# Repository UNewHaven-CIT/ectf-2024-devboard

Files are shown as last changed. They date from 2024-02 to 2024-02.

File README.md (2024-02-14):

# UNewHaven 2024 eCTF
### Rev A

This is a daughterboard for the MAX78000FT development board, designed for the 2024 eCTF competition.

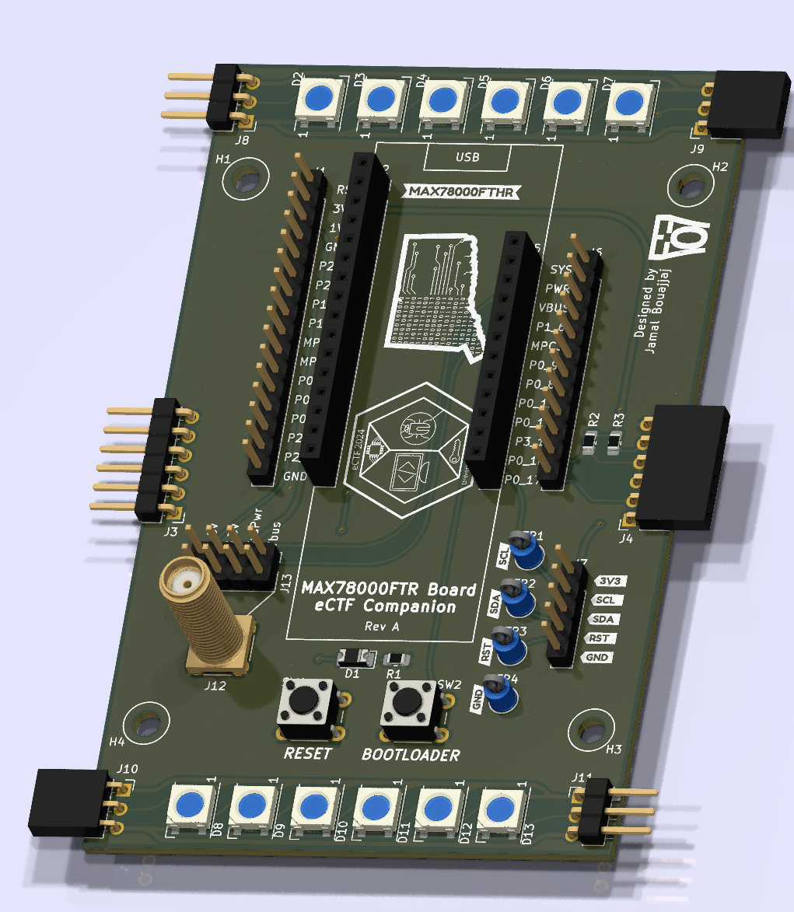
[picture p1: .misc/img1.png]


This was partially inspired by MITRE's own board design, and from a joke gone too far (the leds are what started it all).

# Features
- As the competition has 3 interconnected boards, this design provisions for side-interconnects
- Independent and chain-able WS2812B LEDs on the top of the board, for some true ectf gaming
- Expandable IO for MAX78000FT board
- SMA monitoring for a selection of voltage lines

# License
This project is licensed under GPLv3.

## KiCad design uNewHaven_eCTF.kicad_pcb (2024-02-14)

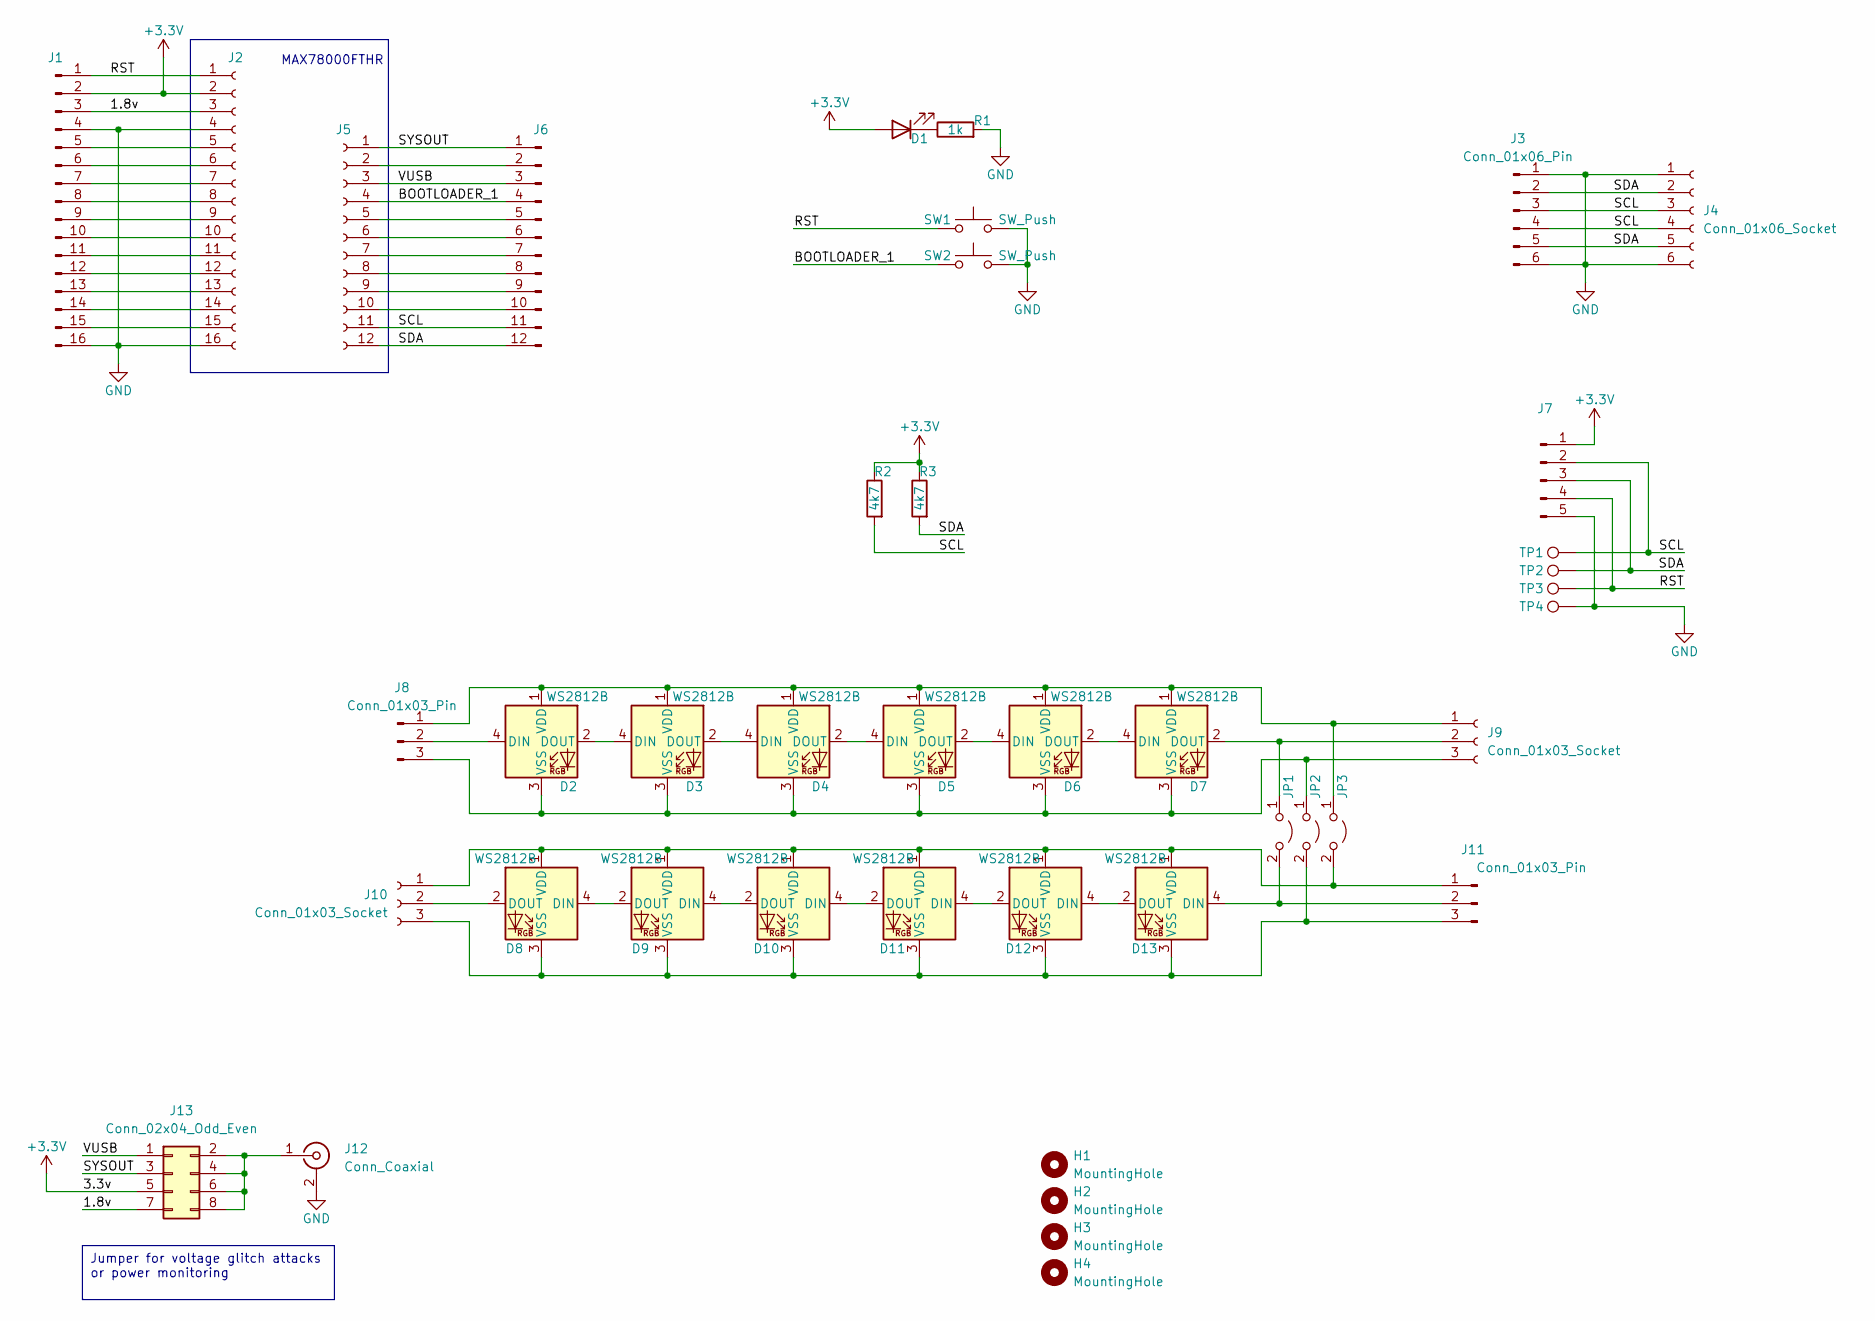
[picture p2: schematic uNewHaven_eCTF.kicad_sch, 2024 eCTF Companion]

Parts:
D1: LED; D_1206_3216Metric_Pad1.42x1.75mm_HandSolder
D2, D3, D4, D5, D6, D7, D8, D9, D10, D11, D12, D13: WS2812B; LED_WS2812B_PLCC4_5.0x5.0mm_P3.2mm
H1, H2, H3, H4: MountingHole; MountingHole_3.2mm_M3_DIN965
J1: Conn_01x16_Pin; PinHeader_1x16_P2.54mm_Vertical
J2: Conn_01x16_Socket; PinSocket_1x16_P2.54mm_Vertical
J3: Conn_01x06_Pin; PinHeader_1x06_P2.54mm_Horizontal
J4: Conn_01x06_Socket; PinSocket_1x06_P2.54mm_Horizontal
J5: Conn_01x12_Socket; PinSocket_1x12_P2.54mm_Vertical
J6: Conn_01x12_Pin; PinHeader_1x12_P2.54mm_Vertical
J7: Conn_01x05_Pin; PinHeader_1x05_P2.54mm_Vertical
J8, J11: Conn_01x03_Pin; PinHeader_1x03_P2.54mm_Horizontal
J9, J10: Conn_01x03_Socket; PinSocket_1x03_P2.54mm_Horizontal
J12: Conn_Coaxial; SMA_Amphenol_132291_Vertical
J13: Conn_02x04_Odd_Even; PinHeader_2x04_P2.54mm_Vertical
JP1, JP2, JP3: Jumper_2_Open; R_0805_2012Metric_Pad1.20x1.40mm_HandSolder
R1: 1k; R_0805_2012Metric_Pad1.20x1.40mm_HandSolder
R2, R3: 4k7; R_0805_2012Metric_Pad1.20x1.40mm_HandSolder
SW1, SW2: SW_Push; SW_PUSH_6mm
TP1, TP2, TP3, TP4: TestPoint; TestPoint_Keystone_5005-5009_Compact

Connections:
+3.3V: D1.2 (A), J1.2, J2.2, J7.1, J13.5, R2.1, R3.1
/1.8v: J1.3, J2.3, J13.7
/BOOTLOADER_1: J5.4, J6.4, SW2.1
/RST: J1.1, J2.1, J7.4, SW1.1, TP3.1
/SCL: J3.3, J3.4, J4.3, J4.4, J5.11, J6.11, J7.2, R2.2, TP1.1
/SDA: J3.2, J3.5, J4.2, J4.5, J5.12, J6.12, J7.3, R3.2, TP2.1
/SYSOUT: J5.1, J6.1, J13.3
/VUSB: J5.3, J6.3, J13.1
GND: J1.4, J1.16, J2.4, J2.16, J3.1, J3.6, J4.1, J4.6, J7.5, J12.2 (Ext), R1.2, SW1.2, SW2.2, TP4.1
unnamed: D1.1 (K), R1.1
unnamed: D2.4 (DIN), J8.2
unnamed: D2.2 (DOUT), D3.4 (DIN)
unnamed: D2.1 (VDD), D3.1 (VDD), D4.1 (VDD), D5.1 (VDD), D6.1 (VDD), D7.1 (VDD), J8.1, J9.1, JP3.1 (A)
unnamed: D2.3 (VSS), D3.3 (VSS), D4.3 (VSS), D5.3 (VSS), D6.3 (VSS), D7.3 (VSS), J8.3, J9.3, JP2.1 (A)
unnamed: D3.2 (DOUT), D4.4 (DIN)
unnamed: D4.2 (DOUT), D5.4 (DIN)
unnamed: D5.2 (DOUT), D6.4 (DIN)
unnamed: D6.2 (DOUT), D7.4 (DIN)
unnamed: D7.2 (DOUT), J9.2, JP1.1 (A)
unnamed: D8.4 (DIN), D9.2 (DOUT)
unnamed: D8.2 (DOUT), J10.2
unnamed: D10.4 (DIN), D11.2 (DOUT)
unnamed: D9.4 (DIN), D10.2 (DOUT)
unnamed: D8.1 (VDD), D9.1 (VDD), D10.1 (VDD), D11.1 (VDD), D12.1 (VDD), D13.1 (VDD), J10.1, J11.1, JP3.2 (B)
unnamed: D8.3 (VSS), D9.3 (VSS), D10.3 (VSS), D11.3 (VSS), D12.3 (VSS), D13.3 (VSS), J10.3, J11.3, JP2.2 (B)
unnamed: D11.4 (DIN), D12.2 (DOUT)
unnamed: D12.4 (DIN), D13.2 (DOUT)
unnamed: D13.4 (DIN), J11.2, JP1.2 (B)
unnamed: J1.5, J2.5
unnamed: J1.6, J2.6
unnamed: J1.7, J2.7
unnamed: J1.8, J2.8
unnamed: J1.9, J2.9
unnamed: J1.10, J2.10
unnamed: J1.11, J2.11
unnamed: J1.12, J2.12
unnamed: J1.13, J2.13
unnamed: J1.14, J2.14
unnamed: J1.15, J2.15
unnamed: J5.2, J6.2
unnamed: J5.5, J6.5
unnamed: J5.6, J6.6
unnamed: J5.7, J6.7
unnamed: J5.8, J6.8
unnamed: J5.9, J6.9
unnamed: J5.10, J6.10
unnamed: J12.1 (In), J13.2, J13.4, J13.6, J13.8

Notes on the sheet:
Jumper for voltage glitch attacks or power monitoring
MAX78000FTHR

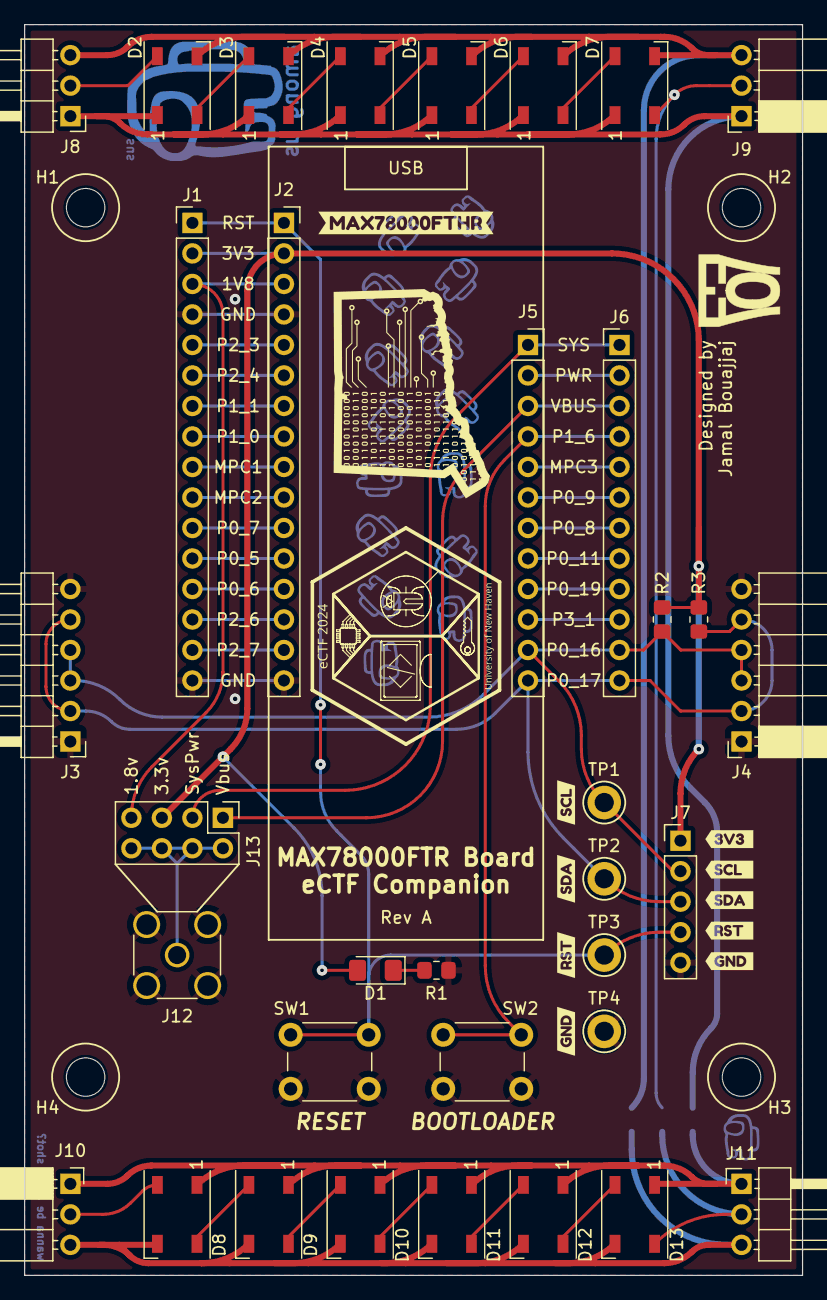
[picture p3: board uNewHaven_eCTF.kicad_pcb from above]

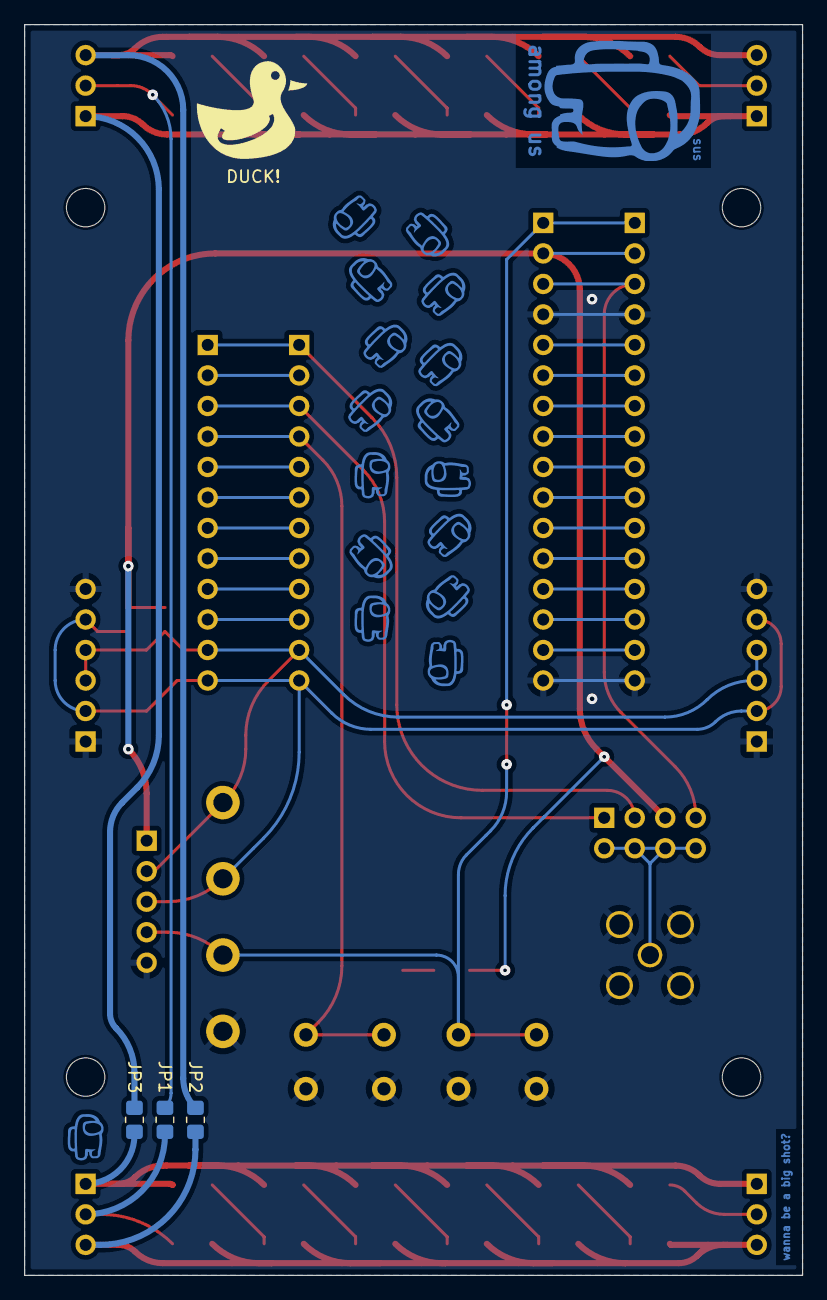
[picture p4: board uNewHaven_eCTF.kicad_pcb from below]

Board: 2 copper layers, 64.8 x 104.1 mm, 52 parts (3 on the bottom side), 47 nets.

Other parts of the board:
kibuzzard-65C1A1E7: G***; kibuzzard-65C1A1E7
kibuzzard-65C1A1F1: G***; kibuzzard-65C1A1F1
kibuzzard-65C1A1F5: G***; kibuzzard-65C1A1F5
kibuzzard-65C1A1FA: G***; kibuzzard-65C1A1FA
kibuzzard-65C1A1FF: G***; kibuzzard-65C1A1FF
kibuzzard-65C19DC0: G***; kibuzzard-65C19DC0
kibuzzard-65C19DCD: G***; kibuzzard-65C19DCD
kibuzzard-65C19DD2: G***; kibuzzard-65C19DD2
kibuzzard-65C19DD8: G***; kibuzzard-65C19DD8
kibuzzard-65C19E6E: G***; kibuzzard-65C19E6E
